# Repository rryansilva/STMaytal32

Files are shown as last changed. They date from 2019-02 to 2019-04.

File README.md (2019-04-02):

# STMaytal32
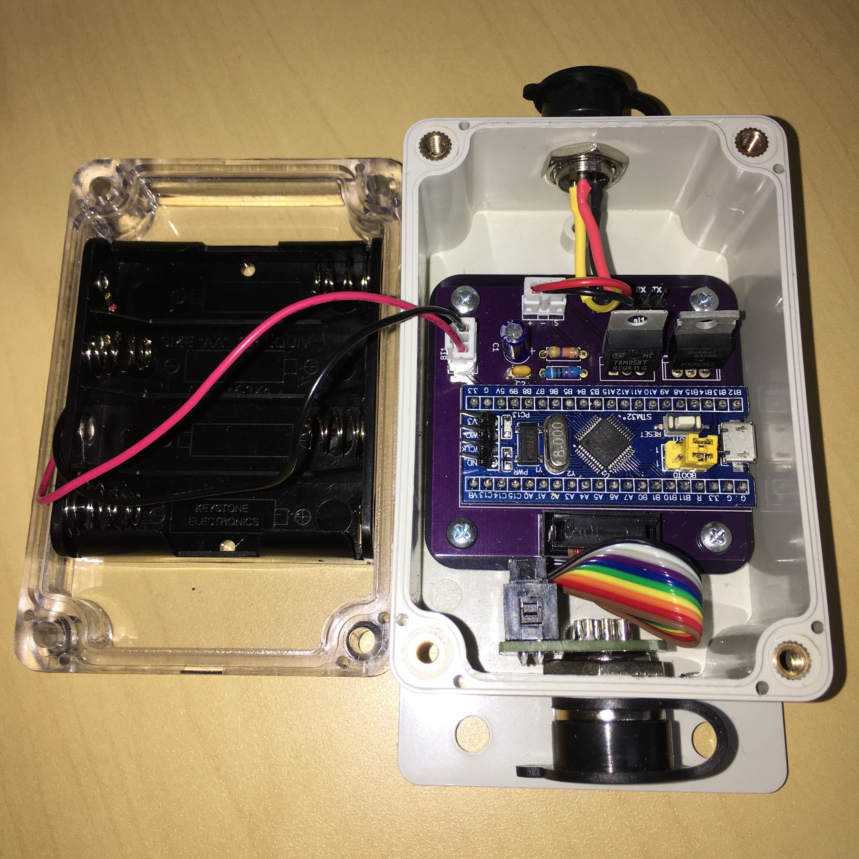
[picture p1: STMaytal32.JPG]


STMaytal32 is a new generation proof-of-concept design for water pressure telemetry for underresourced water utilities. It uses a standard automotive oil pressure sender to read pressure and send this to a server where it can inform better operation of a utility. It follows up on the original proof-of-concept designed called Maytal and the designs and iterations that followed from Indonesian innovators supported by a grant from the USAID IUWASH Plus project.

This is just a proof-of-concept and should not be taken to be the right or best way to address the questions raised in the testing of earlier designs. 

## Design features
STMaytal32 responds to some challenges to scale that were identified in testing some of the earlier water pressure telemetry designs:

* *Modularity*. Earlier designs were integrated into one large box that was sometimes difficult to place near enough to a pipe outlet while still getting power and a communications signal. This led to some installations where very long cords were added to the pressure sender, changing the resistance and increasing the amount of power necessary to drive the sensor. STMaytal32 puts the sensing and computational functions in one box, and the communications function in another, independently powered box. This allows the two to be placed at a distance from one another without interfering with readings or signal (provided the UART signal between the two remains readable). It also enables different communications technologies to be used in different installation contexts.
* *Bill of Materials*. The STMaytal32 design is centered on the "Blue Pill" STM32 development board which is common in Indonesia (IDR 70,000 on Tokopedia) and on the worldwide market (US$1.48 on Aliexpress). The Blue Pill includes an oscillator to drive the onboard RTC peripheral, obviating the need for a separate RTC to wake the unit from sleep. Efforts have been taken to reduce extraneous hardware that would add cost to the design. 
* *Power*. Field placement of earlier designs revealed that in practice, utilities often want to position these units in places such as in manholes or among complex piping systems that do not readily allow for solar or mains power. By using the relatively power-efficient STM32 and eliminating unnecessary hardware, the main module of the STMaytal32 can be powered by 4 AA batteries, which should run the unit for several months before needing replacement. 
* *Communications*. Earlier designs used GSM networks for communications, which, while effective, would impose operating costs and administrative burden for utilities. The communications module described here uses LoRaWAN for communications, which should enable utilities to manage their own simple, inexpensive networks which can also be used to collect data from future sensors.

## Breakdown
### Core module
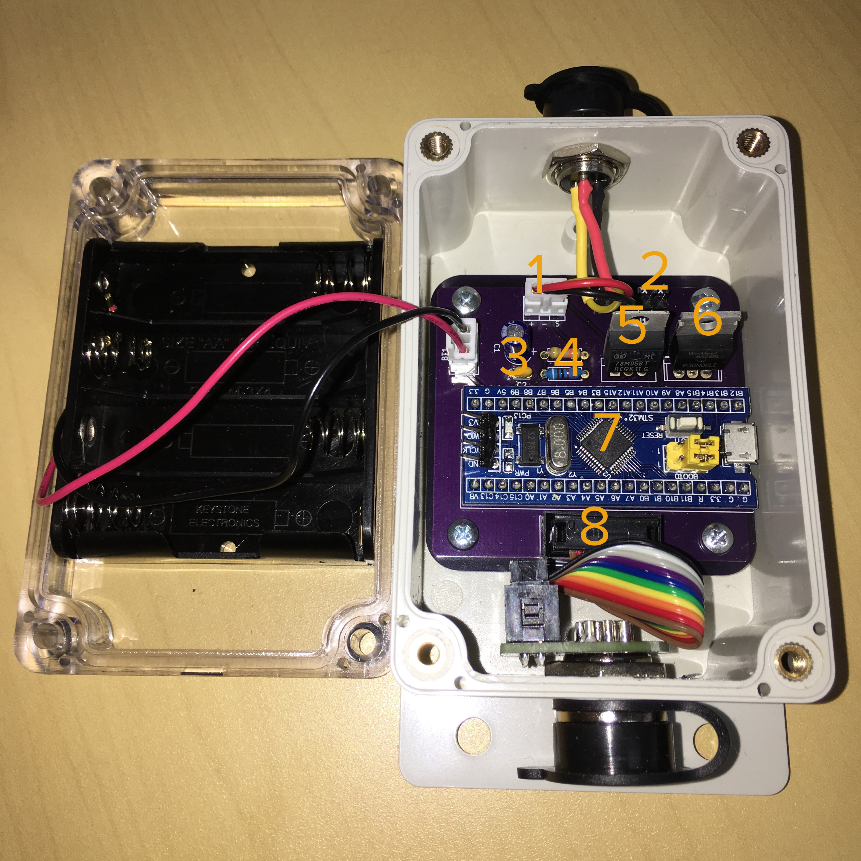
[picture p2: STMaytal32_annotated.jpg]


1. *1x03 connector*. To enable the pressure sender to be easily attached and detached.
2. *Serial1 breakout.* Pins to the STM32's Serial1 port are broken out here to facilitate debugging.
3. *Smoothing capacitors*. To reduce variations in supply from the AA batteries.
4. *Voltage divider*. To convert the 5V signal from the pressure sender to a 3.3V equivalent signal.
5. *Voltage regulator*. The regulator on the Blue Pill supplies 3.3V of dubious reliability. This supplies 5V direct from the AA batteries.
6. *Power MOSFET*. Cuts power to the pressure sender while not in use.
7. *"Blue Pill" STM32 development board*. Note that the PWR LED has been desoldered to save power.
8. *1x10 JTAG-style connector*. To connect to a GX16-10 aviation connector on the enclosure, which connects this with the communications module.

### Communications module


The communications module is just an Adafruit RFM9x LoRa breakout board and an Adafruit Solar LiPo charger board, interfaced with a 1x10 JTAG-style connector to facilitate connection to the core module. More work to source locally-appropriate and less expensive parts is called for in the near future.

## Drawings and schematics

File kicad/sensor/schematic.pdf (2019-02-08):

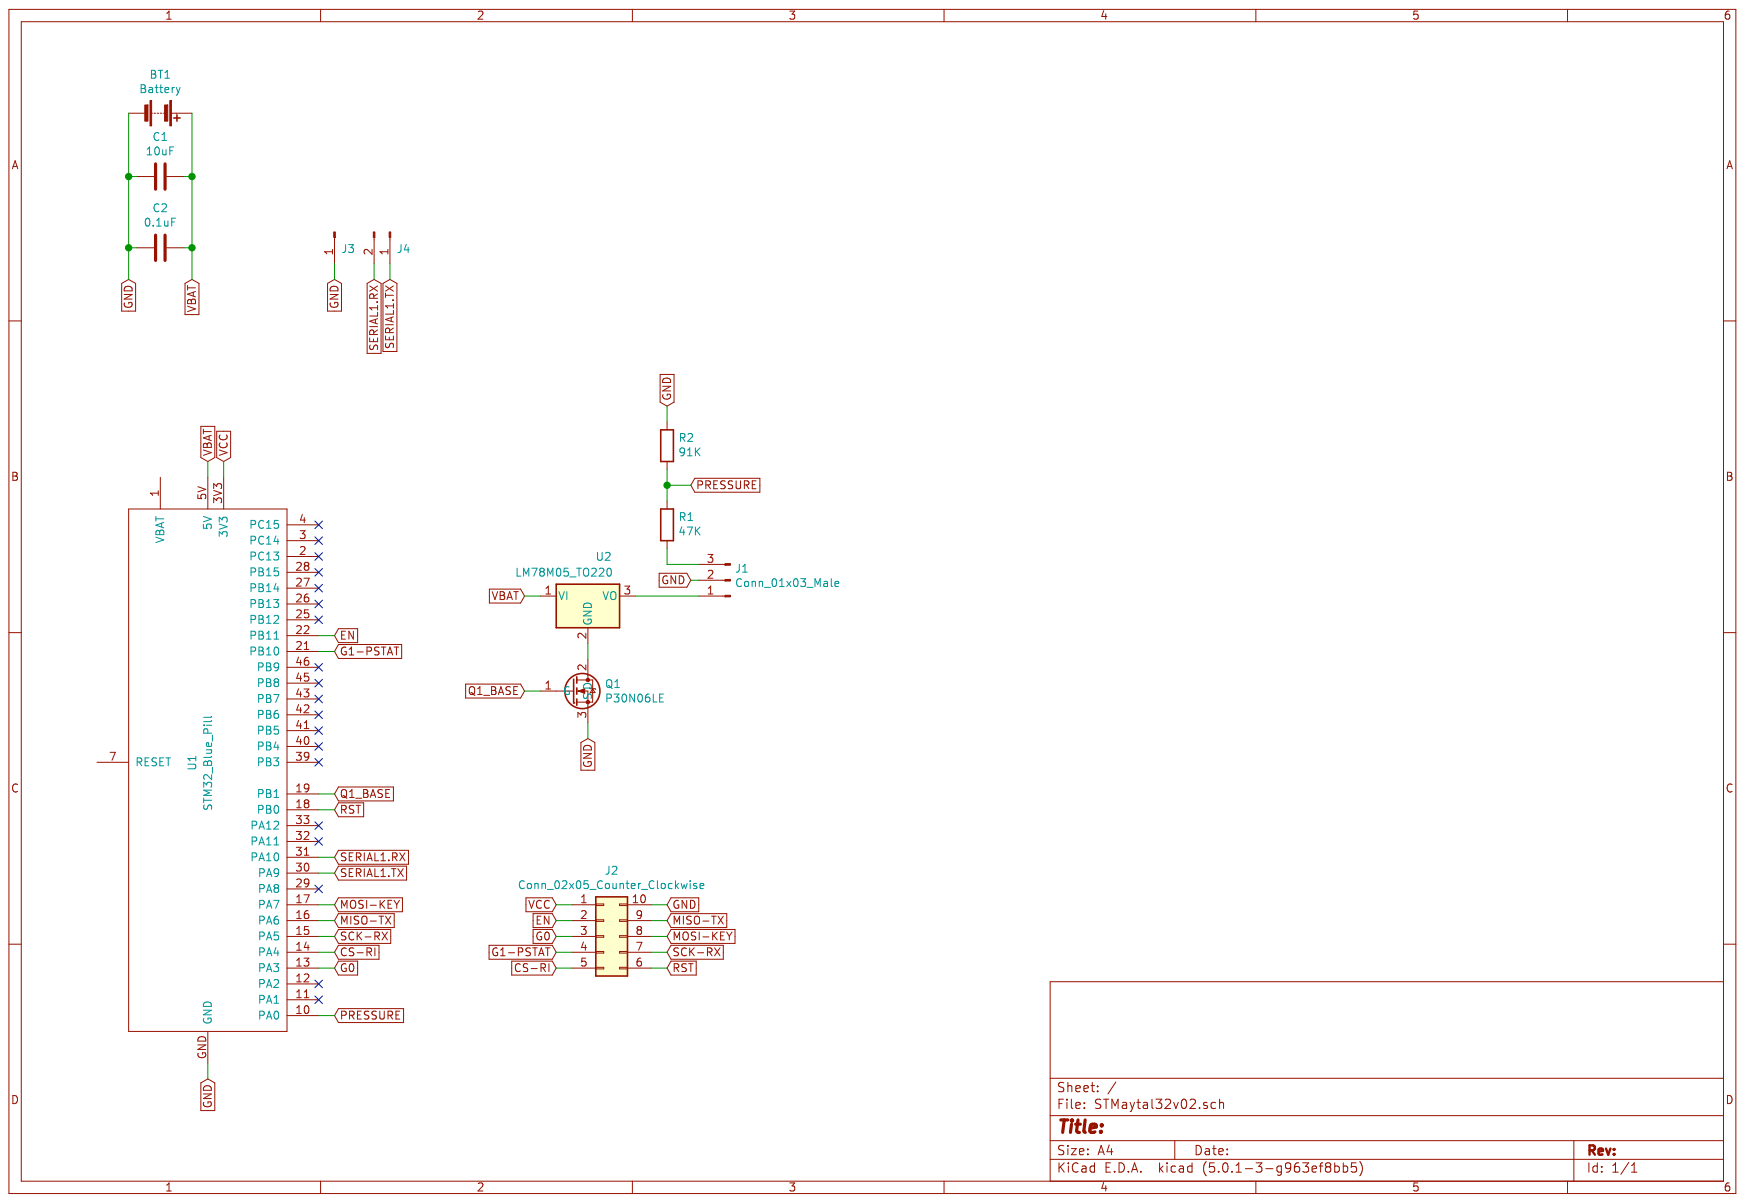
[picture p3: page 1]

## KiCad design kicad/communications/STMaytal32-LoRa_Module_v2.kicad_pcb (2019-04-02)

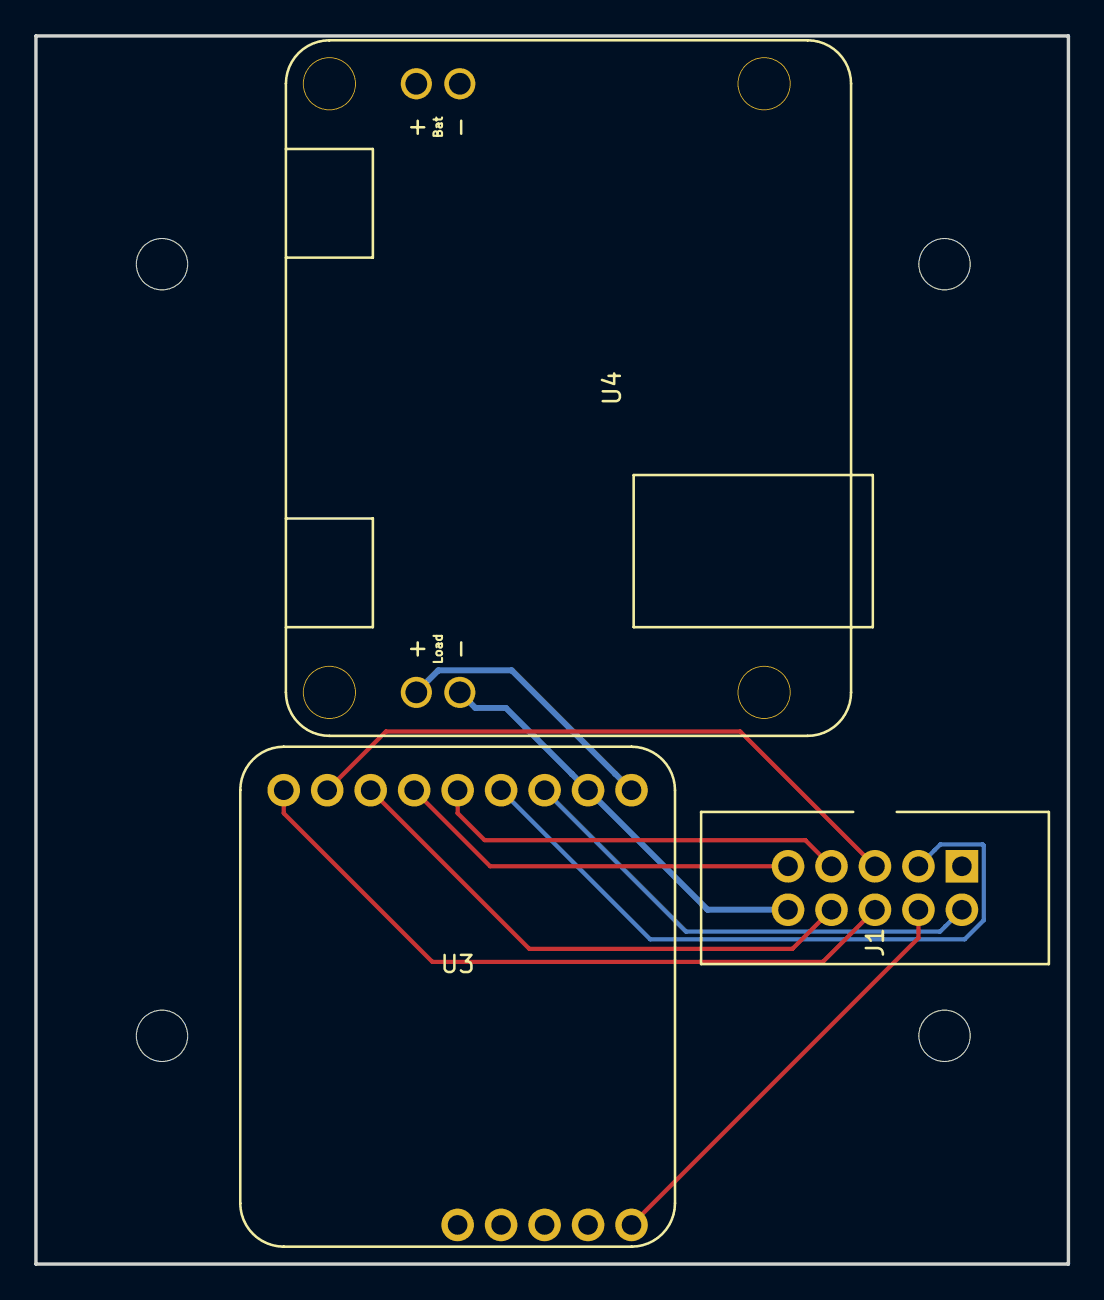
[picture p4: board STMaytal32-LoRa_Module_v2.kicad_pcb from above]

Board: 2 copper layers, 60.3 x 71.8 mm, 3 parts (0 on the bottom side), 10 nets.

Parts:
J1: Conn_02x05_Counter_Clockwise; 2x05-JTAG-type-connector
U3: Adafruit_LoRa_Breakout
U4: Adafruit_LiPoly_Solar; Adafruit_LiPo_Solar

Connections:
CS-RI: J1.5, U3.8
EN: J1.2, U3.3
G0: J1.3, U3.5
G1-PSTAT: J1.4, U3.10
GND: J1.10, U3.2, U4.4
MISO-TX: J1.9, U3.6
MOSI-KEY: J1.8, U3.7
unnamed: U3.1, U4.3
RST: J1.6, U3.9
SCK-RX: J1.7, U3.4

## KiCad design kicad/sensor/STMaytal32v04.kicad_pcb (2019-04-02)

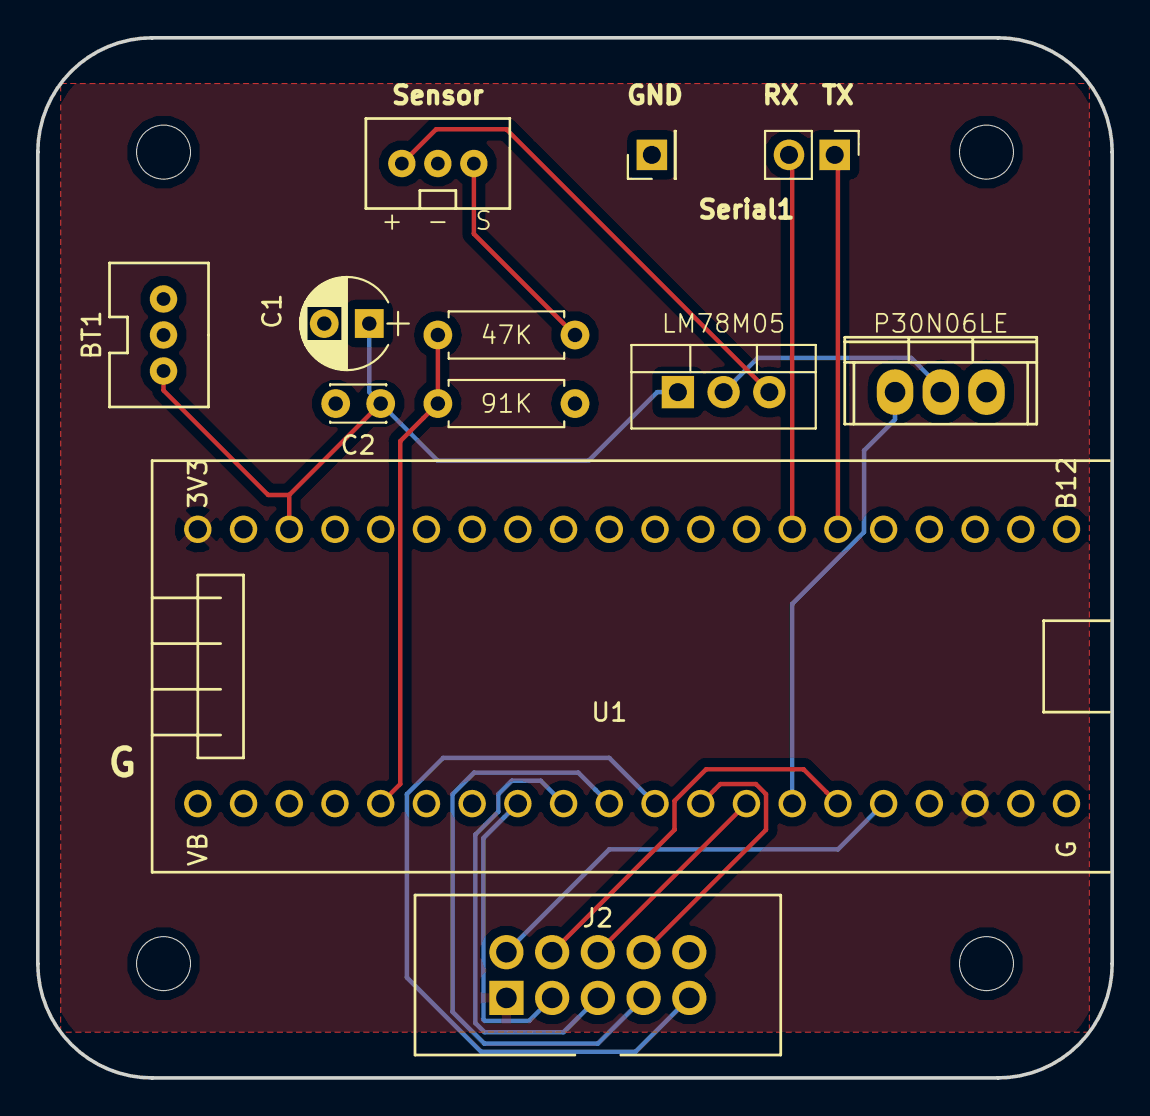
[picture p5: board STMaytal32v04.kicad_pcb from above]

Board: 2 copper layers, 59.7 x 57.8 mm, 12 parts (0 on the bottom side), 18 nets.

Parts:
BT1: Battery; Keystone_3POS_2mm
C1: 10uF; CP_Radial_D5.0mm_P2.50mm
C2: 0.1uF; C_Disc_D3.0mm_W2.0mm_P2.50mm
J1: Conn_01x03_Male; JST-PH-2.0-3_pin
J2: Conn_02x05_Counter_Clockwise; 2x05-JTAG-type-connector
J3: Conn_01x01_Male; Pin_Header_Straight_1x01_Pitch2.54mm
J4: Conn_01x02_Male; Pin_Header_Straight_1x02_Pitch2.54mm
Q1: P30N06LE; TO-220
R1: 47K; R_Axial_DIN0207_L6.3mm_D2.5mm_P7.62mm_Horizontal
R2: 91K; R_Axial_DIN0207_L6.3mm_D2.5mm_P7.62mm_Horizontal
U1: STM32_Blue_Pill
U2: LM78M05_TO220; TO-220-3_Vertical

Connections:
CS-RI: J2.5, U1.14
EN: J2.2, U1.22
G0: J2.3, U1.13
G1-PSTAT: J2.4, U1.21
GND: BT1.1, C1.2, C2.2, J1.2, J2.10, J3.1, Q1.3, R2.2, U1.GND
MISO-TX: J2.9, U1.16
MOSI-KEY: J2.8, U1.17
unnamed: J1.1, U2.3
unnamed: J1.3, R1.1
unnamed: Q1.2, U2.2
PRESSURE: R1.2, R2.1, U1.10
Q1_BASE: Q1.1, U1.19
RST: J2.6, U1.18
SCK-RX: J2.7, U1.15
SERIAL1.RX: J4.2, U1.31
SERIAL1.TX: J4.1, U1.30
VBAT: BT1.3, C1.1, C2.1, U1.5V, U2.1
VCC: J2.1, U1.3V3

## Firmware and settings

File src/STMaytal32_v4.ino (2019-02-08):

static const byte PROGMEM DEVEUI[8]   =   { 0x79, 0xB1, 0xFA, 0x85, 0x03, 0x18, 0xAD, 0x00 }; //  LSB
static const byte PROGMEM APPEUI[8]   =   { 0xF4, 0x0C, 0x01, 0xD0, 0x7E, 0xD5, 0xB3, 0x70 }; //  LSB
static const byte PROGMEM APPKEY[16]  =   { 0xDE, 0xB6, 0xA3, 0x22, 0x4F, 0x23, 0xA0, 0x5D, 0x37, 0xD7, 0xFB, 0xA0, 0x65, 0x18, 0x89, 0x1A };  //  MSB

#define VERSION "0.03"
#define INTERVAL 15       //  Time, in minutes, between uploads

//  - - - - - - - - - - - - - - - - - - - - - - - - - - - - - - - - - - - - - - - - - - - - - - - - - - - - - - - - - - - - - - - - - - - - - - - - 

#include <lmic.h>           //  LoRaWAN-MAC-in-C library
#include <hal/hal.h>        //  Hardware abstraction layer library
#include <EEPROM.h>         //  To store derived LoRaWAN session keys
#include <SPI.h>            //  For communication with RFM95
#include <RTClock.h>        //  For using the onboard real-time clock
#include <libmaple/scb.h>   //  System control byte definitions

//  Backup memory registers to hold LoRaWAN session information from boot to boot
#define BOOTWORD      (*(uint32_t *)0x40006C04)   //  Will allow us to verify if this is the initial boot
#define SEQNOUP       (*(uint32_t *)0x40006C08)   //  LoRaWAN upload sequence count
#define SEQNODN       (*(uint32_t *)0x40006C0C)   //  LoRaWAN download sequence count
#define TXCHNL        (*(uint32_t *)0x40006C10)   //  TX channel as received from ADR
#define DATARATE      (*(uint32_t *)0x40006C14)   //  Data rate as received from ADR
#define ADRTXPOW      (*(uint32_t *)0x40006C18)   //  Transmit power as received from ADR

#define PRESCALER 0xF0000   //  Two ticks per minute for the RTC

void os_getDevEui(u1_t* buf) {memcpy_P(buf, DEVEUI, 8);}
void os_getArtEui(u1_t* buf) {memcpy_P(buf, APPEUI, 8);}
void os_getDevKey(u1_t* buf) {memcpy_P(buf, APPKEY, 16);}

const uint16_t MAGICWORD = 0xBEEF;           //  Vegetarians may prefer CAFE

uint8_t payload[2];
static osjob_t sendjob;

const uint16_t nwkSKeyIndex = 0x10;
const uint16_t appSKeyIndex = 0x30;
const uint16_t netidIndex   = 0x40;
const uint16_t devaddrIndex = 0x41;

uint32_t  sleepTime;
const int Q1 = PB1;           //  Transistor for transducer
const int en = PB11;          //  LoRa module enable
const int pressurePin = PA0;  //  Pressure transducer output
const int led = PC13;

boolean initialBoot   =   false;
boolean transmission  =   false;

// Pin mapping for RFM95 module
const lmic_pinmap lmic_pins = {
  .nss = PA4,
  .rxtx = LMIC_UNUSED_PIN,
  .rst = PB0,
  .dio = {PA3, PB10, LMIC_UNUSED_PIN}
};

#define DEBUG

RTClock rtc(RTCSEL_LSE, PRESCALER + 1);   //  Instantiate Low Speed External clock with prescaler



void setup() {
  Serial1.begin(115200);

  wait(1000);

  Serial1.println();
  Serial1.println("---------------------------------------------------------------------------------");
  Serial1.print(F("STMaytal32 v"));
  Serial1.println(VERSION);
  Serial1.print(__DATE__);   //  Compile date and time helps identify software uploads
  Serial1.print(F(" "));
  Serial1.println(__TIME__);

  wait(2000);
  
  /*  TODO: Validate that alarm is still set before sleep -- we don't want to set alarm after upload
  *  because the timing of readings and uploads will get erratic. We want a nice steady cadence. */
  rtc.createAlarm(&AlarmFunction, rtc.getTime() + (INTERVAL * 2) - 1);  //  Set wakeup alarm
  
  pinMode(led, OUTPUT);
  pinMode(Q1, OUTPUT);
  pinMode(en, OUTPUT);
  
  #ifdef DEBUG
    digitalWrite(led, LOW);
  #endif

  digitalWrite(en, HIGH);   //  Turn on LoRa radio
  wait(1000);               //  Give the radio a moment to shake off the sleepies
  
  EEPROM.PageBase0 = 0x801F000;
  EEPROM.PageBase1 = 0x801F800;
  EEPROM.PageSize  = 0x800;

  os_init();                //  

  /*   If MAGICWORD is not already in the backup registers, we know the unit is booting from scratch
   *   and we need to start the LoRaWAN upload sequence count from zero. We'll also need to store the
   *   NwkSKey and AppSKey for use on later wakes once we have them.  */   
  if(BOOTWORD != MAGICWORD) {
    Serial1.println("First boot.\n");
    LMIC_reset();           //  Reset the MAC state. Session and pending data transfers will be discarded.
    EEPROM.init();          //  Initialize the emulated EEPROM
    EEPROM.format();        //  Format the emulated EEPROM
    initialBoot = true;
    BOOTWORD = MAGICWORD;
  } else {
    Serial1.println("Welcome back.\n");
    restoreSession();
    initialBoot = false;
  }
  
  LMIC_setClockError(MAX_CLOCK_ERROR * 1 / 100);  //  Let LMIC compensate for +/- 1% clock error*/

  LMIC_setAdrMode(1);
  LMIC_setLinkCheckMode(1);
  /*LMIC_setDrTxpow(DR_SF9,20);
  LMIC.dn2Dr = DR_SF9;*/

  #if defined(CFG_eu868)
    LMIC_setupChannel(0, 868100000, DR_RANGE_MAP(DR_SF12, DR_SF7),  BAND_CENTI);      // g-band
    LMIC_setupChannel(1, 868300000, DR_RANGE_MAP(DR_SF12, DR_SF7B), BAND_CENTI);      // g-band
    LMIC_setupChannel(2, 868500000, DR_RANGE_MAP(DR_SF12, DR_SF7),  BAND_CENTI);      // g-band
    LMIC_setupChannel(3, 867100000, DR_RANGE_MAP(DR_SF12, DR_SF7),  BAND_CENTI);      // g-band
    LMIC_setupChannel(4, 867300000, DR_RANGE_MAP(DR_SF12, DR_SF7),  BAND_CENTI);      // g-band
    LMIC_setupChannel(5, 867500000, DR_RANGE_MAP(DR_SF12, DR_SF7),  BAND_CENTI);      // g-band
    LMIC_setupChannel(6, 867700000, DR_RANGE_MAP(DR_SF12, DR_SF7),  BAND_CENTI);      // g-band
    LMIC_setupChannel(7, 867900000, DR_RANGE_MAP(DR_SF12, DR_SF7),  BAND_CENTI);      // g-band
    LMIC_setupChannel(8, 868800000, DR_RANGE_MAP(DR_FSK,  DR_FSK),  BAND_MILLI);      // g2-band
  #elif defined(CFG_us915)
    // NA-US channels 0-71 are configured automatically
    LMIC_selectSubBand(1);
  #endif
  
  wait(5000);

  transmission = false;
  
  #ifdef DEBUG
  digitalWrite(led, LOW);
  #endif
  
  uint16_t psi = readPressure();   //  Get sensor data

  payload[1] = psi >> 8;
  payload[0] = psi;

  Serial1.println();
  
  do_send(&sendjob);        //  Start job
  
  while(1) {
    os_runloop_once();
    
    if(transmission == true) {
      break;
    }
    
    /*if(joined == true) {
      break;
    }*/
  }
  
  Serial1.print("PSI: ");
  Serial1.println(psi);
  Serial1.print("Payload[0]: ");
  Serial1.println(payload[0], BIN);
  Serial1.print("Payload[1]: ");
  Serial1.println(payload[1], BIN);  

  Serial1.print("netid: ");
  Serial1.println(LMIC.netid);
  Serial1.print("devaddr: ");
  Serial1.println(LMIC.devaddr, HEX);

  Serial1.print("Seqnoup: ");
  Serial1.println(LMIC.seqnoUp);
  Serial1.print("Seqnodown: ");
  Serial1.println(LMIC.seqnoDn);
  Serial1.println();
  Serial1.print("NwkSKey: ");
  for(int i = 0; i < 16; i++) {
    Serial1.print(LMIC.nwkKey[i], HEX);
    Serial1.print(" ");
  }

  Serial1.println();
  
  Serial1.print("AppSKey: ");
  for(int i = 0; i < 16; i++) {
    Serial1.print(LMIC.artKey[i], HEX);
    Serial1.print(" ");
  }
  
  SEQNOUP = LMIC.seqnoUp;
  SEQNODN = LMIC.seqnoDn;
  
  wait(100);

  #ifdef DEBUG
    Serial1.println("\n\rSleeping...");
  #endif

  Serial1.end();
  digitalWrite(en, LOW);      //  Turn off LoRa radio

  #ifdef DEBUG
    digitalWrite(led, HIGH);
  #endif
 
  wait(100);
   
  enterSleepMode();
}



void loop() {
  while(1);                 //  Should never reach
}



void wait(unsigned long ms) { //  Non-blocking delay function
  unsigned long period = millis() + ms;
  while(millis() < period) {
    Serial1.flush();
  }
}



uint16_t readPressure() {    //  This is the original Maytal code for a 5V input
  digitalWrite(Q1, HIGH);     //  Switch on transducer
  wait(3000);                 //  Let transducer settle
  
  float pressure = 0.00;
  uint16_t adcReading = analogRead(pressurePin);
  uint16_t rawVoltage = map(adcReading, 0, 4095, 0, 5000);

  //  Validate that analogRead is between 0.5v-4.5v range of transducer
  if(rawVoltage < 500 || rawVoltage > 4500) {
    pressure = 0;
  } else {
    pressure = (map(rawVoltage, 500, 4500, 0, 174));  //  Convert to PSI
  }

  digitalWrite(Q1, LOW);      //  Switch off transducer to save power

  #ifdef DEBUG
    Serial1.print("ADC reading: ");
    Serial1.println(adcReading);
    Serial1.print("Raw voltage: ");
    Serial1.println(rawVoltage);
    Serial1.print("Converted pressure: ");
    Serial1.println(pressure);
  #endif

  return(int)pressure;
}

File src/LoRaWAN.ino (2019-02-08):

void onEvent(ev_t ev) {
  Serial1.print(os_getTime());
  Serial1.print(": ");
  switch(ev) {
  case EV_SCAN_TIMEOUT:
    Serial1.println(F("EV_SCAN_TIMEOUT"));
    break;
  case EV_BEACON_FOUND:
    Serial1.println(F("EV_BEACON_FOUND"));
    break;
  case EV_BEACON_MISSED:
    Serial1.println(F("EV_BEACON_MISSED"));
    break;
  case EV_BEACON_TRACKED:
    Serial1.println(F("EV_BEACON_TRACKED"));
    break;
  case EV_JOINING:
    Serial1.println(F("EV_JOINING"));
    break;
  case EV_JOINED:
    Serial1.println(F("EV_JOINED"));
    writeKeys();      //  Write the keys to emulated EEPROM
    break;
  case EV_RFU1:
    Serial1.println(F("EV_RFU1"));
    break;
  case EV_JOIN_FAILED:
    Serial1.println(F("EV_JOIN_FAILED"));
    break;
  case EV_REJOIN_FAILED:
    Serial1.println(F("EV_REJOIN_FAILED"));
    break;
  case EV_TXCOMPLETE:
    Serial1.println(F("EV_TXCOMPLETE (includes waiting for RX windows)"));
    if (LMIC.txrxFlags & TXRX_ACK)
      Serial1.println(F("Received ack"));
    if (LMIC.dataLen) {
      Serial1.println(F("Received "));
      Serial1.println(LMIC.dataLen);
      Serial1.println(F(" bytes of payload"));
    }
    Serial1.print("txChn1 ");
    Serial1.print(LMIC.txChnl);
    Serial1.print(", datarate ");
    Serial1.print(LMIC.datarate);   
    Serial1.print(", txPower: ");
    Serial1.print(LMIC.adrTxPow);

    TXCHNL        = LMIC.txChnl;
    DATARATE      = LMIC.datarate;
    ADRTXPOW      = LMIC.adrTxPow;
    
    transmission = true;
    break;
  case EV_LOST_TSYNC:
    Serial1.println(F("EV_LOST_TSYNC"));
    break;
  case EV_RESET:
    Serial1.println(F("EV_RESET"));
    break;
  case EV_RXCOMPLETE:
    // data received in ping slot
    Serial1.println(F("EV_RXCOMPLETE"));
    break;
  case EV_LINK_DEAD:
    Serial1.println(F("EV_LINK_DEAD"));
    break;
  case EV_LINK_ALIVE:
    Serial1.println(F("EV_LINK_ALIVE"));
    break;
   default:
    Serial1.println(F("Unknown event"));
    break;
  }
}



void do_send(osjob_t* j){
  // Check if there is not a current TX/RX job running
  if(LMIC.opmode & OP_TXRXPEND) {
    Serial1.println(F("OP_TXRXPEND, not sending"));
  } else {
    // Prepare upstream data transmission at the next possible time.
    LMIC_setTxData2(1, payload, sizeof(payload)-1, 0);
    Serial1.println(F("Packet queued"));
  }
  // Next TX is scheduled after TX_COMPLETE event.
}

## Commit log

2019-02-22 Pressure reading now works
2019-02-22 Removed reference to pressure readings not working
2019-04-02 Updated board footprints
    [STMaytal32-LoRa_Module_v2-B.Cu.gbr, STMaytal32-LoRa_Module_v2-B.Mask.gbr, STMaytal32-LoRa_Module_v2-Edge.Cuts.gbr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]
